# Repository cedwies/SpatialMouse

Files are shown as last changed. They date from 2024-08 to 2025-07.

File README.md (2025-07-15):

## Spatial Mouse:

The spatial mouse is a clever connection between a computer mouse and a VR controller. 

There are some useful use cases for this product. 
A good example could be a designer, who designs 3D objects on a virtual monitor. The designer can use the spatial mouse for his normal 2D design program but also lift it up and grab, drag and rotate the virtual object the designer is working on, without the need of taking off the VR glasses and looking for VR controller. 

Another, simpler use case could be someone working not at a the office with multiple monitors but in a café, where you dont have any external monitors. A virtual monitor setup would be nice. In this case this person could use the spatial mouse to perform the normal computer work but also control VR things like dragging screens and windows to another place or changing something in the virtual surrounding.

## Repository Structure

| Directory | Purpose |
|---|---|
| `Project` | Everything related to your project. |
| `Project/Concept` | Everything related to the concept or design of your project (ideas, drawings, mockups, mind maps, etc.). |
| `Project/Electronics` | Everything related to the electronics of your project (circuit diagrams, datasheets, etc.). |
| `Project/Mechanical` | Everything related to the mechanical aspect of your project (CAD, blueprints, datasheets, assembly, etc.). |
| `Project/Software` | The software aspect of your project. Most likely source code. |
| `Weekly Reports` | Weekly status updates as Markdown files. |
| `Weekly Reports/Figures` | Pictures or videos for your weekly reports. |

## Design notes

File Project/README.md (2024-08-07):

# PhysComp SS24 - SpatialMouse

The Spatial Mouse is a combination of a VR controller and a computer mouse. In the folder you can find some information about our current work.

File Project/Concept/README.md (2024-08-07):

# Spatial Mouse Concept

## Overview

The Spatial Mouse is an innovative input device that combines the functionality of a traditional computer mouse with a VR controller. This unique combination allows for seamless transitions between 2D and 3D interactions in virtual environments.

## Key Features

- Functions as a standard 2D mouse on flat surfaces
- Transforms into a 3D VR controller when lifted
- Seamless transition between 2D and 3D interactions
- Compatible with both traditional desktop applications and VR environments

## Use Cases

### 1. 3D Design and Modeling

Ideal for designers working on 3D objects in virtual environments:
- Use as a regular mouse for 2D design software
- Lift to manipulate 3D objects (grab, drag, rotate) without switching devices
- Eliminates the need to remove VR headset to locate separate controllers

### 2. Virtual Workspaces

Perfect for professionals working in mobile or space-constrained environments:
- Operate normally for standard computer tasks
- Easily control virtual monitors and windows in a VR workspace
- Adjust virtual surroundings without additional equipment

## Benefits

- Increased productivity by reducing device switching
- Enhanced workflow in mixed 2D/3D environments
- Improved portability for VR-enhanced work setups

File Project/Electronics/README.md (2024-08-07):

# PhysComp SS24 - SpatialMouse - Electronics

# Custom Sensor Integration

This project demonstrates the integration of custom sensors with a microcontroller board.

## Wiring Diagram

The included wiring diagram illustrates the connections between various components:

- Multiple sensor inputs (D6, D7, D8, D9)
- Power supply (VBUS)
- Ground (GND)
- Power supply (VIN)
- Additional modules (represented by rectangular blocks)

While the diagram is a simplified representation, it communicates the overall connection scheme, allowing for quick understanding and implementation.

## Physical Implementation

The accompanying photo shows the actual wiring implementation. Key features include:

- Multi-colored wires for easy identification
- Compact wiring layout to minimize space requirements
- Use of standard connectors for modularity and ease of assembly/disassembly

This physical setup demonstrates the transition from concept to practical application.

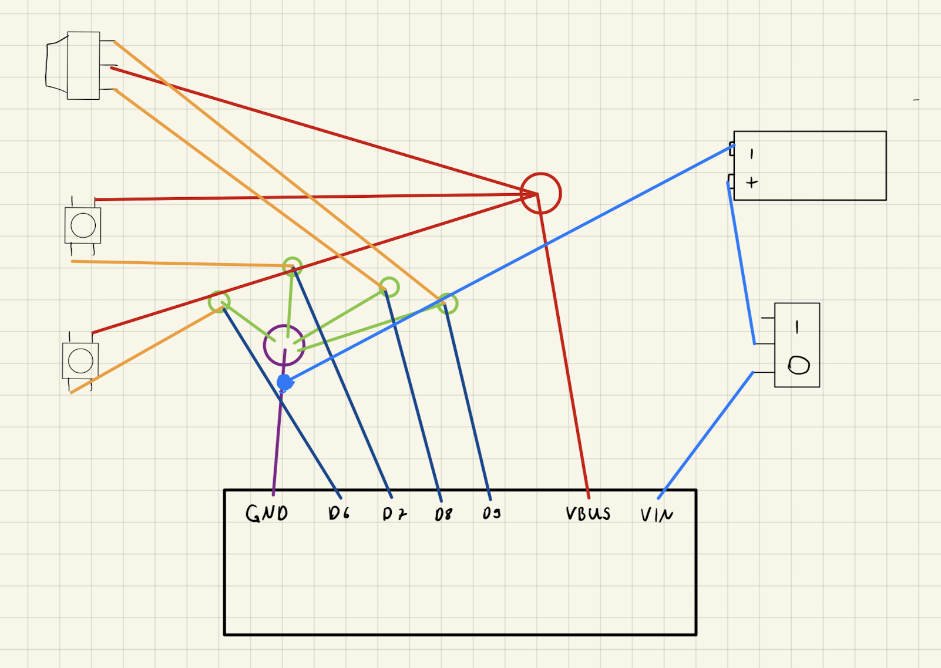
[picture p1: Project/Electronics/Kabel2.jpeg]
Kabel


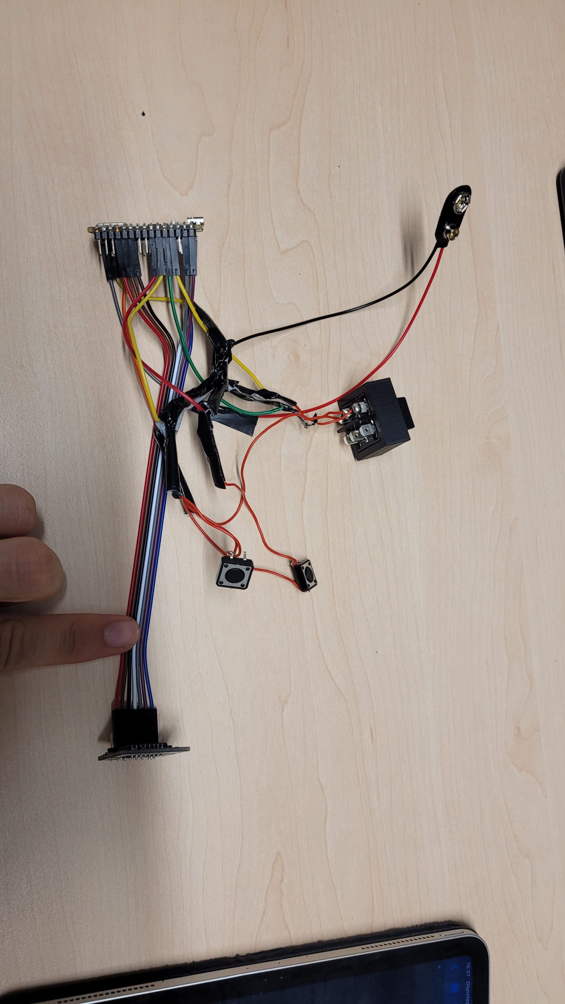
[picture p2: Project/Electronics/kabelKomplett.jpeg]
Kabel2


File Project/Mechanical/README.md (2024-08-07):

# PhysComp SS24 - SpatialMouse - Mechanical

Below you'll find images and the Fusion 360 code for the 3D model of our second iteration Spatial Mouse prototype:

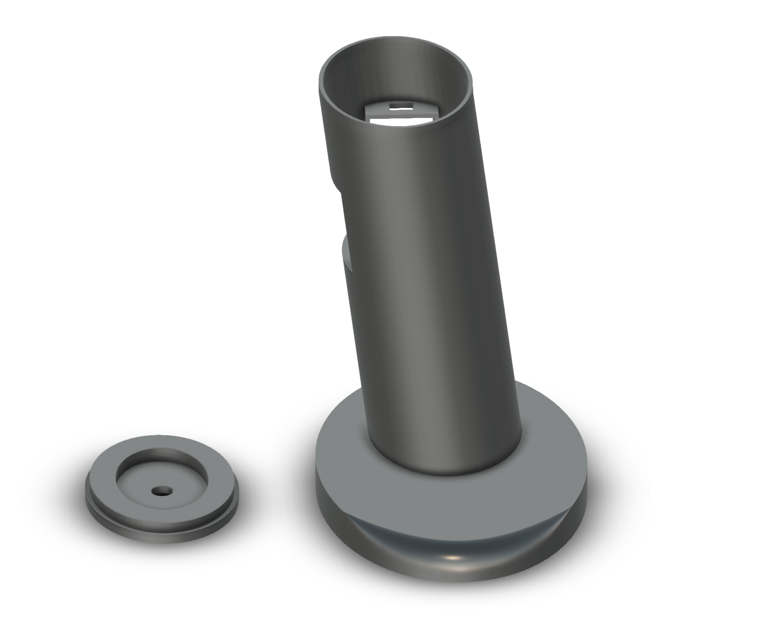
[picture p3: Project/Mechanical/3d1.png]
SpatialMouse1


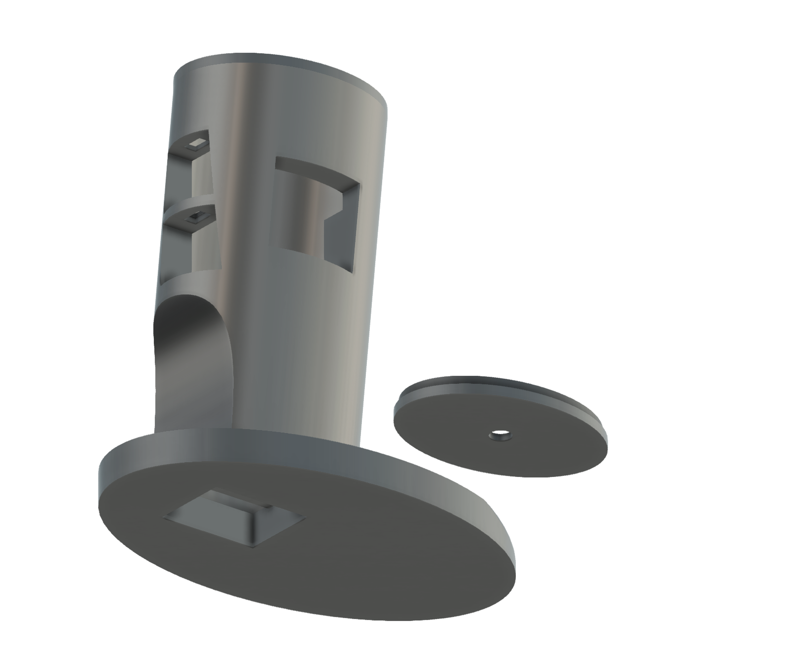
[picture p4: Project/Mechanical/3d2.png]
SpatialMouse2


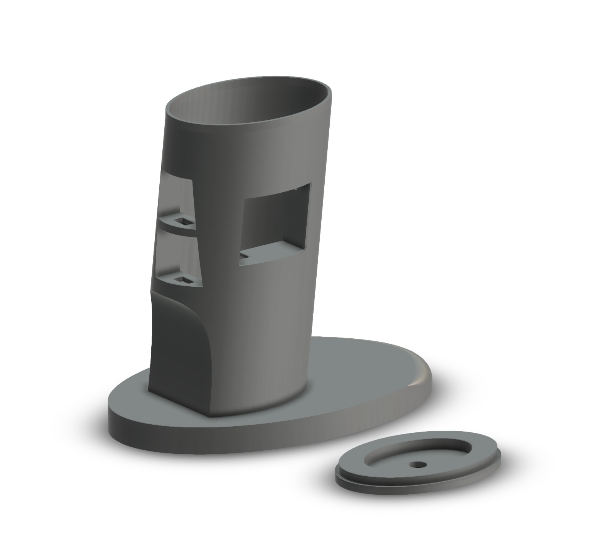
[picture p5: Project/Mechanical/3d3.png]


This is our newes iteration of the 3D model for the Spatial Mouse:

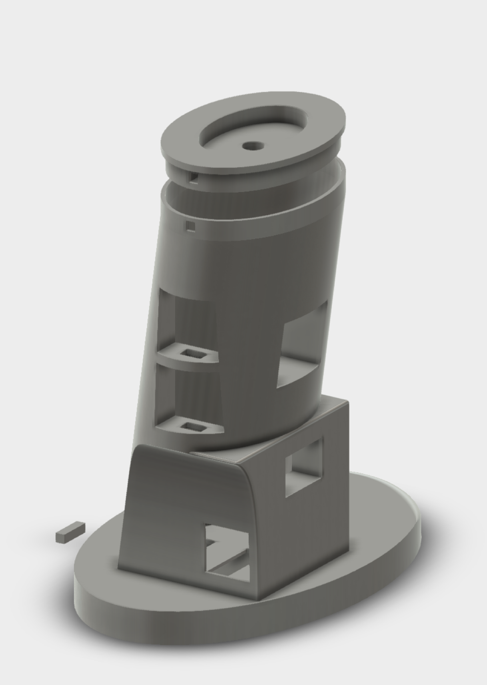
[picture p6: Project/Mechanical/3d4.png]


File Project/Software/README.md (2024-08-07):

This section contains the code for both the Arduino microcontroller and the Unity project, which together form the core components of our custom VR input device system.

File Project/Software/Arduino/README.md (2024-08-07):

# PhysComp SS24 - SpatialMouse - Software

This section contains the code for the Arduino Nano ESP32. The code operates a Bluetooth mouse featuring two buttons, a scroll switch, and a mouse sensor. The mouse sensor detects whether the device is on the ground or in the air and transmits this information to another Bluetooth device. When the mouse is lifted, the buttons have alternative functions and do not operate as standard mouse clicks.

We worked with code from here (for our mouse sensor): 
https://github.com/mrjohnk/PMW3389DM

And with the BLE Mouse Library:
https://github.com/T-vK/ESP32-BLE-Mouse

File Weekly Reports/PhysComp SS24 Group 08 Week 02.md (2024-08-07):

# PhysComp SS24 Group 8 - Week 1

## Progress Report

### What we achieved this week

This week, our task was to work with Arduino and learn how simple electric circuits work. Since we both don't have any experience with hardware and micro controllers, it was new and interesting. We started with the basic tutorials on the Arduino page. After learning the basics of how a simple electric circuit is built and what different components have what functionality, we started to build our own few circuits (see pictures). At the end of this session, we came to the section where we had to run a test program on an Arduino micro controller, where the LED on the controller started to blink. After achieving this, the session was over.

AWeekOne
AWeekOne

### What we could not achieve this week

Unfortunately, we were unable to completely finish the course. We needed some time to actually figure out how all individual components work together. One mayor reasons for this was that we needed a substantial amount of time to get things up and running, especially finding the correct online course took us some time. 

However, the main problem was that we frequently got caught up in playing around with the components. We did not follow the course strictly, but rather started to experiment a lot at certain times. While we believe this to be a good way of learning, for the next time we would try to adhere to the course a little bit more strictly.

### What we plan to do for the coming week

We would like to continue to familiarise ourselves with the hardware, especially by experimenting with the Arduino micro controller. Up to this point we only worked with non-programmable electric circuits. We are excited to bridge the gap between programming and hardware, in order to maximise our expertise for the upcoming weeks and primarily the final prototype.

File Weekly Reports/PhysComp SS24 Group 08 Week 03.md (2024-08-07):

# PhysComp SS24 Assignment - Week 3

> **Deadline:** 07.05.2023, 23:59 CEST

## Weekly Progress Report

1. **First concept:** 

We started by brainstorming different ideas and concepts in order to create viable sketches and to rule out poor design choices. To achieve this, we focused on asking ourselves "What is important?". By asking that question repeatedly, we found that ease of use, low weight and ergonomic feeling should be our main priorities, since users will likely hold the device in their hands for a prolonged period of time.

Regarding our sketches, we designed them by forming them out of knead. We found this to be the best approach, as we could easily check how they feel inside a users hand.  This would not have been possible with drawings. We created 4 different models, which were the results of our brainstorming session.

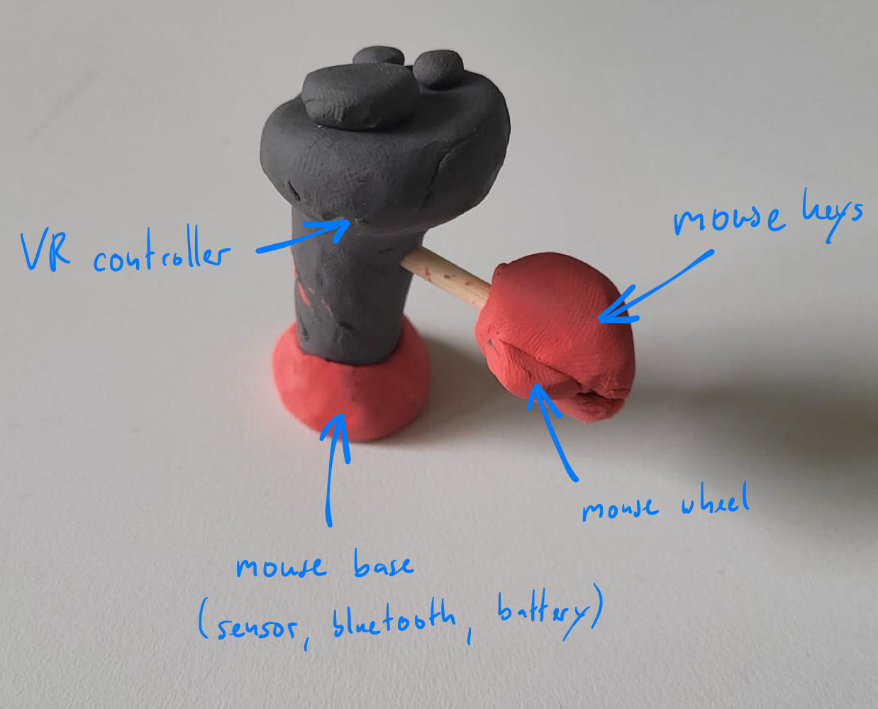
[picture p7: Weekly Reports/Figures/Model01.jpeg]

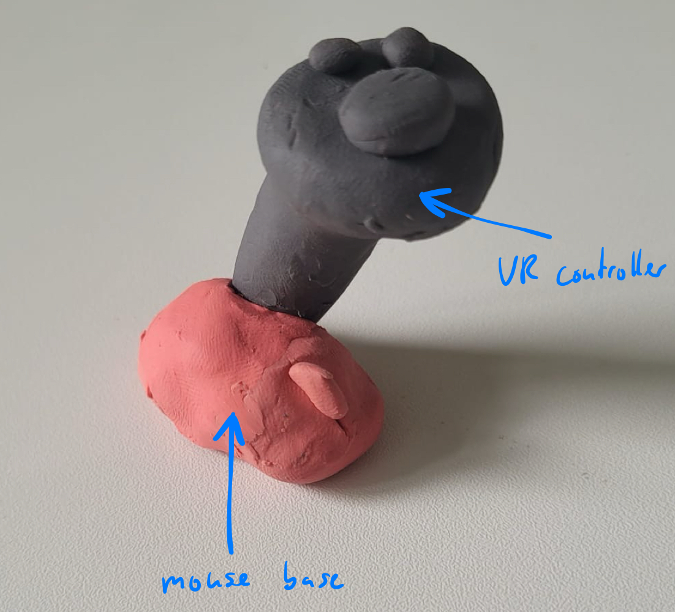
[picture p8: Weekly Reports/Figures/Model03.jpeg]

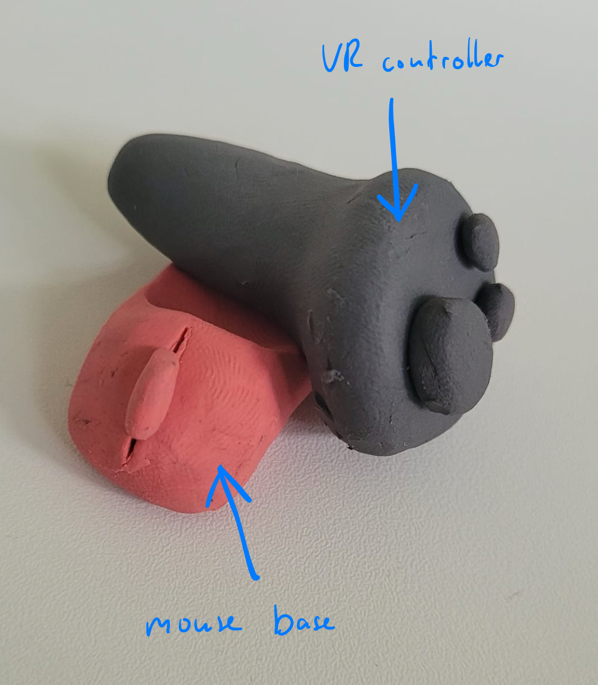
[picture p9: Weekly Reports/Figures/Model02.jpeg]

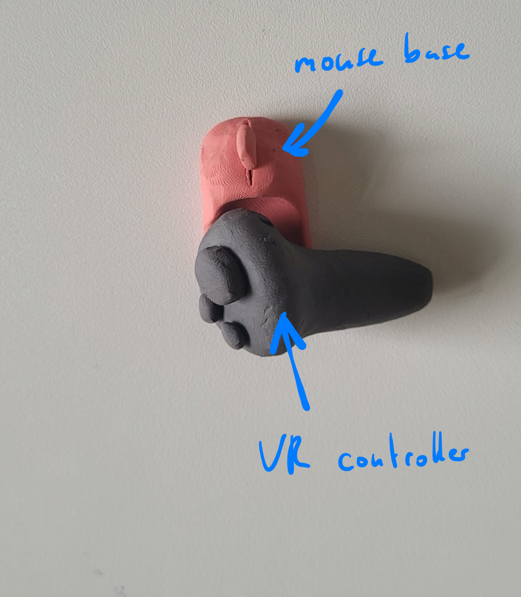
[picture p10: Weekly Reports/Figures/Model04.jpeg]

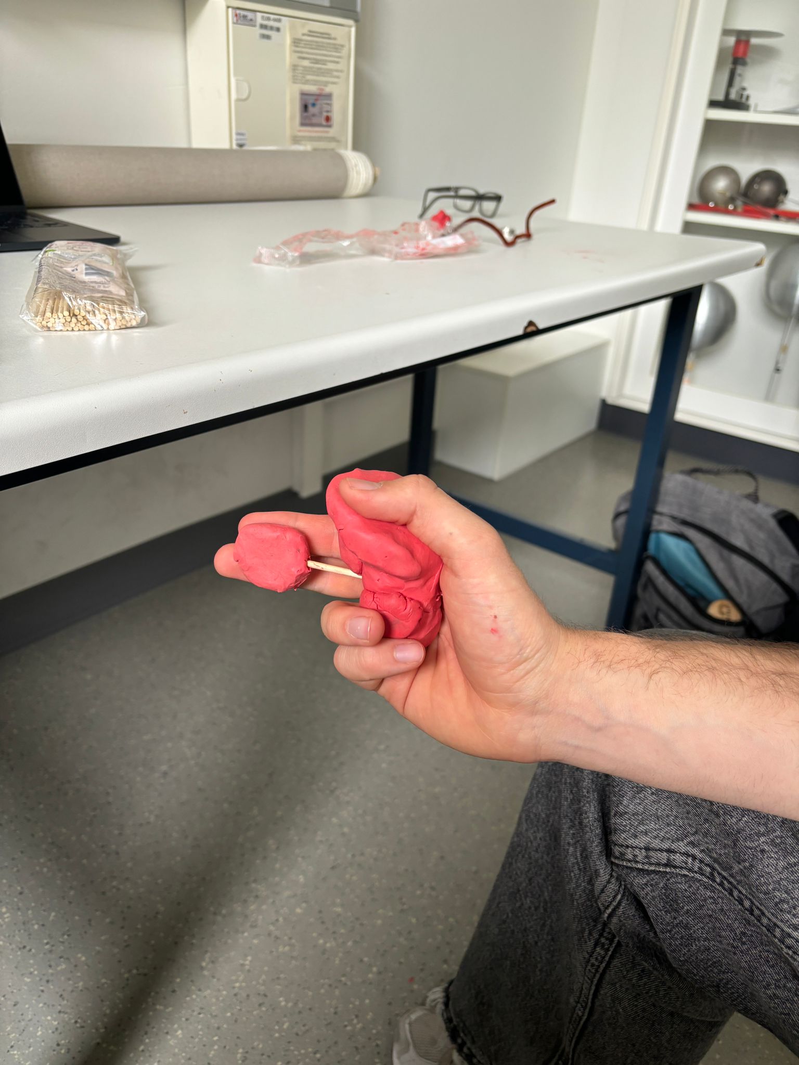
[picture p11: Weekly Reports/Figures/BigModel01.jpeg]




Picture 1: User (wearing a VR-Glasses) using a mouse

Picture 2: The user has to take down the VR-Glasses in order to switch to the VR-Controller

Picture 3: User using a VR-Controller as input device

Picture 4: User has to take down VR-Glasses again in order to switch the input device

Picture 5: 2-in-1 Spatial-Mouse gets handed to the user

Picture 6: User throws Mouse and VR-Controller in the trash

Picture 7: User using Spatial-Mouse as a mouse

Picture 8: User using Spatial-Mouse as a VR-Controller

2. **Objects/Idea Collection:** 







3. **First component list** 

| Item | Status | Example |
|---|---|---|
| VR Controller | Already ordered | - |
| Mouse (Bluetooth) | Already ordered and arrived | - |
| Modelling material (Knead) | Not yet ordered | https://rb.gy/tvhnu7 |
| 3D printing material | Not yet ordered | https://rb.gy/vp8pg3 |

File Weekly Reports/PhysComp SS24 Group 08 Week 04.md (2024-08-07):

# PhysComp SS24 Assignment - Week 4

> **Deadline:** 14.05.2024, 23:59 CEST

## Weekly Progress Report

1. **Progress report:**

    We continued to think about our prototype. After brainstorming a little, we looked for an old plastic film to protect the VR controller we brought today. With the wrapped-up controller, we tried out different creations of how we could combine it with a modified mouse.

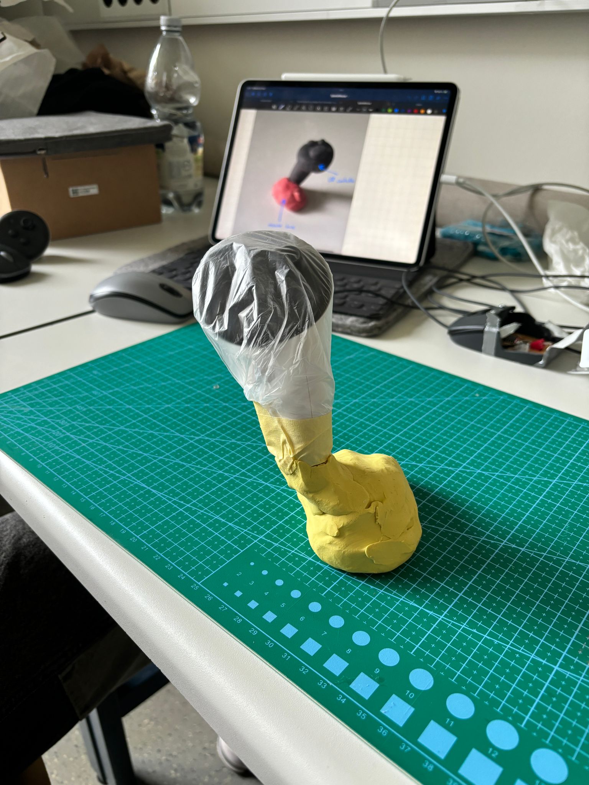
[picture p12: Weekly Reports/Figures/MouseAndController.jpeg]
    

    After a talk with Prof. Feutner we decieded to change our plans. While we were previously focusing on combining a mouse and a VR-Controller, we tried to deviate from this idea and tried to think more "outside the box". By planning on building the device ourselves (instead of just using a existing VR-Controller), we were able to come up with more unique shapes and new solutions (picture below). This week, we successfully thought about what would be needed to build our prototype. We especially focused on the components that we need for this task. The main change is, that we have a completely new shape, rather than working with finished products.

    

    In this picture one can see our first ideas of how the Spatial Mouse could look like. One can also see the major differences compared to having the computer mouse and VR-Controller combined.

    Unfortunately, we were unable to find exact models of all the components we need. Some hardware components (such as the mouse sensor) are hard to find. Furthermore, while we have a good general understanding of what we are trying to achieve, we did not yet go into very much detail. Part of the reason is, that going into detail requires us to know our hardware components. 

    Our plans for next week are to finish the list of hardware components that we need to order and to decied on one of the shaped for our first prototype (At the moment we are leaning towards the right one).

    **Norman's Design Principles:**

    Visibility: We have made the buttons and switches on the device clearly visible and easily distinguishable. The input buttons (primary and secondary trigger) shall be placed in similar locations compared to a traditional VR-Controller, making the purpose evident to the user.

    Feedback: We incorporate tactile feedback into the buttons and switches, providing a satisfying click or bump when activated. While a traditional VR-Controller has buttons with gradual pressability, we will for now focus on "all or nothing" buttons, for improved feedback.

    Constraints: We have designed the device with physical constraint that guide the user's actions. The shape and size of the device naturally fit the user's hand, encouraging a comfortable and ergonomic grip. Furthermore, the mouse plate at the bottom does not allow for any other sensable way of putting the device on the table, other that how it is intended to be placed.

    Mapping: We have mapped the devices controls to closely match the user's expectations and mental models. The input buttons will be placed similarily to the buttons of traditional VR-Controllers, and the mouse wheel will have an almost identical shape compared to traditional mouse wheels, following established conventions and best practices.

    Constistencty: The behaviour of the buttons shall remain consistent in each mode. For example, one mouse button should always be for left click, while the other button should always be for right click. In VR mode, the buttons consistently map to specific actions or functions within the virtual environment, such as grabbing objects or navigating menus.

    Affordance: The physical design of the device affords its intended use. The shape and form factor of the stick suggest that it can be gripped and manipulated like a handheld controller. The flat mouse plate on the bottom affords placement on a desk surface for mouse functionality. The buttons and switches are sized and shaped to invite pressing, clearly indicating their interactive nature.

    Siginifiers: We have included clear signifiers on the device to communicate its capabilities and mode of operation. The mode switch button shall be distinctively marked to signify its purpose. The device's overall appearance and branding shall signify its dual functionality as a VR-Controller and computer mouse.

2. **Refined component list:** 

| Item | Status | Example |
|---|---|---|
| Vive Tracker | Present at University | - |
| Arduino ESP 32 | Not yet ordered | https://shorturl.at/juJKL |
| Mouse Sensor (including breakout board) | Not yet ordered | Still searching for an example, hard to find |
| 3D printing material | Present at University | - |
| Buttons | Still deciding which types we need | - | 
| Battery | Not certain which power supply is needed | - |

Note: The main components (which have to be ordered) are the Arduino ESP 32, the mouse sensor and the breakout board. 
We expect to find everything else at the University (at least everything that we think is needed so far, such as cables etc.). Next week, we'll take a closer look at our component list and aim to wrap it up.

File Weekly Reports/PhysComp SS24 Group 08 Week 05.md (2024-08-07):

# PhysComp SS24 Assignment - Week 5

> **Deadline:** 21.05.2024, 23:59 CEST

## Weekly Progress Report

1. **Project Concept**

    After our presentations, we first discussed the feedback we received. Then, we went downstairs to gather some materials for building a prototype of our new design idea. Once we found the materials we needed, we quickly started working on the sketch.
    
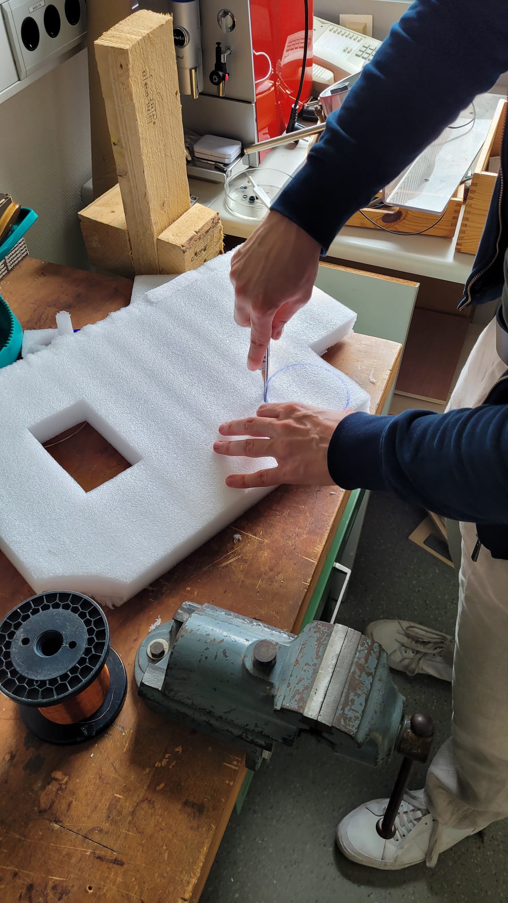
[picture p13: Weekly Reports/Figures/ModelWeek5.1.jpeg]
    

    Figure 1: Creating our first physical prototype based on our new design.
    
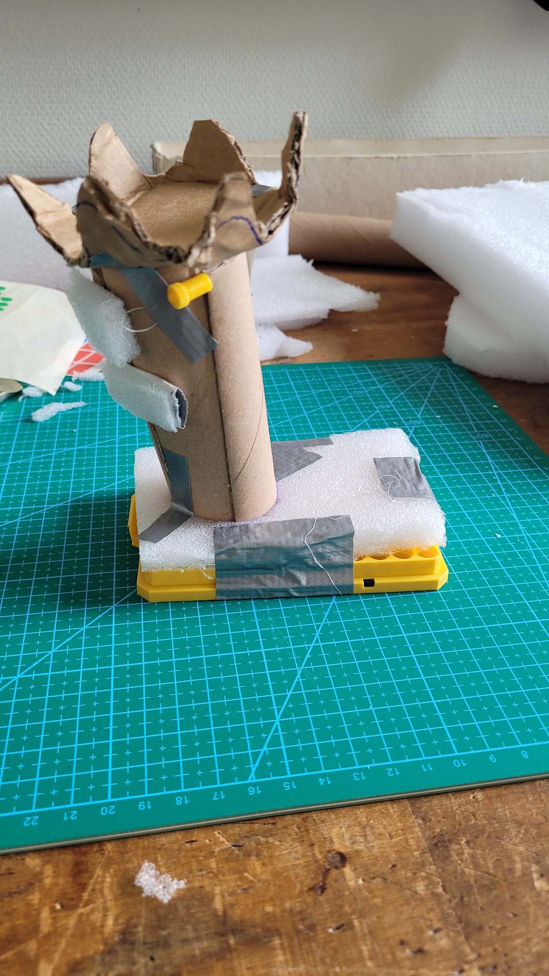
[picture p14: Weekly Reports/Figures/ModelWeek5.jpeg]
    

    Figure 2: Finished the first physical protoype. White buttons in the front, plate for mouse sensor at the bottom, yellow pin representing the mouse wheel.
    The crown on top represents the vive tracker.
    
    We were satisfied with the result, especially since we were unsure about how the mouse positions would feel. One problem we realised after building the prototype was that different hand sizes affect how well you can use the spatial mouse. We will have to find a way to allow hands of different sizes to comfortably grab the spatial mouse.

    After building our prototype, we talked to two other groups, exchanged feedback, and showed both of them our paper model of the spatial mouse. This was helpful as it provided additional feedback and led to interesting discussions about our design choice. We also tested the tilted (visible in the picture of our prototype) design which was suggested as feedback by group 4 and were surprised by the difference regarding the feeling when one is grabbing onto the device. Due to the small tilt, the spatial mouse feels more natural and the stress on the users wrist is reduced.

    Unfortunately, we did not have time to discuss the component list. We will try to focus on that again in the future.

2. **Current component list:** 

| Item | Status | Example |
|---|---|---|
| Vive Tracker | Present at University | - |
| Arduino ESP 32 | Not yet ordered | https://shorturl.at/juJKL |
| Mouse Sensor (including breakout board) | Not yet ordered | Still searching for an example, hard to find |
| 3D printing material | Present at University | - |
| Buttons | Still deciding which types we need | - | 
| Battery | Not certain which power supply is needed | - |

Note: The main components (which have to be ordered) are the Arduino ESP 32, the mouse sensor and the breakout board. 
We expect to find everything else at the University (at least everything that we think is needed so far, such as cables etc.). Next week, we'll take a closer look at our component list and aim to wrap it up.

## Feedback Report
1. **Concept Presentation**

We received helpful and insightful feedback on our concept presentation. First, feedback was given regarding the buttons (user inputs) of our device.
While we already thought about not using buttons with gradual feedback on purpose, clues were given about which button would be serving as the left or right mouse click respectively. By asking the question "Which button do you plan on using for the left mouse click?" it was brought to our attention that we did not yet think this through enough and we might need to spend a little bit more time on that matter.

Next, it was mentioned that the spatial mouse may lead to an urge of lifting the device even when making use of the computer mouse use case. This would be far from ideal. However, when handing the prototype to other groups, we were not able to confirm this feedback. So while we will keep an eye out for this issue, we are not going to immediately deal with it, since it may not actually be a problem when using the device.

Lastly, we received feedback on the general design of our spatial mouse. We were asked what other shapes there might be, since the shapes of our prototypes were either strongly inspired by a computer mouse or by a VR controller. This feedback was familiar, since this was our main issue for the past two weeks. We were asked again for "outside of the box" solutions. 

Regarding solutions, one might be able to incorporate buttons which support two modes. One with tactile feedback, as well as one mode where the buttons only give gradual feedback. The user can then switch between the two modes, depending on which feedback he wants to receive upon pressing the buttons. Furthermore, one can think about new shapes again. Although we already thought about shapes extensively, there might be creative and ideally suited designs which we did not yet uncover. However, this would only be hypothetical, since after evaluating thoroughly, our current design is the most promising solution.

2. **Peer Evaluation**

For the peer evaluation we partnered up with Group 2 and 4.

With both groups we handed over our prototype and allowed them to play around freely, without giving them too many hints about how the device is intended to be used. Fortunately, both groups intuitively grabbed the device in the way it was intended to, placing their fingers on the correct buttons. This was a "silent" feedback for us, that the current shape of our spatial mouse successfully invites for a correct usage.

Both groups mentioned the ergonomic feeling during usage. While group 4 only suggested we might incorporate a small tilt for a more natural feeling, group 2 was sceptical at first regarding the vertical use of a computer mouse. They mentioned that a user might need some time to adjust to this new way of interacting with a computer mouse, but agreed that this might be a less significant issue when we showed them that there are vertical computer mouses for ergonomical reasons on the market. Another suggestion was that maybe one can achieve a design, were the user can turn the device in order to be able to use the mouse in the traditional position (horizontal), i.e. by turning the device 90 degrees, while making sure that the user does not have to change his grip. This feedback was again driven by the way in which they currently interact with a computer mouse but confirmed our assumption, that the ability to have one grip for both use cases is an essential feature and should be focused during further development of our prototype. 

Regarding given feedback for group 4, we evaluated the position of their control panel. While it is easily accessible when located on one of the arm pits, the arm pit can no longer be used to rest on. We suggested sticking it to the side of an arm pit and allow it to be flipped up and down when it is (not) needed. We also questioned the use case of the "lost chair" function, which shall allow the chair to come to the user on its own. We argued that we do not think that this feature will be used frequently, since we do not ask ourselves "where is my chair right now?". Almost every time we exactly know where our chair is located. Group 4 appreciated our feedback and told us, the feature could be useful for blind people. We agreed to the usefulness of such a feature for blind users, but also mentioned that blind users cannot really interact with a control panel which is not adapted to blind users, so they should pay attention to this detail. 

Group 2 asked our opinion on where to put the electronics in their device. While their current favourite was a circular plate on the bottom of the glass, we argued that this design can lead to several problems. Firstly, one has to be careful not to make the device too heavy. Users will lift the glass frequently and when the glass becomes too heavy, a user might be annoyed. Secondly, the circular plate had a larger diameter than the glass itself (at least in their prototype). In our feedback we mentioned that tables can be quite full with plates, multiple wine (and normal) glasses, forks, etc. So it would be ideal if the device does not need any additional horizontal space (vertical space is less tragic in our opintion). All in all our feedback focused on the importance of keeping the size which needs to be added to the glass to a minimum.

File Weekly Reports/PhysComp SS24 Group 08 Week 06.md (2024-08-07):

# PhysComp SS24 Assignment - Week 6

> **Deadline:** 04.06.2024, 23:59 CEST

## Weekly Progress Report
1.	**3D Printing:** Post *screenshots* of your 3D model(s) and briefly describe what you did, or whether you struggled with something. Upload your final *3D your models*, so we can print all next week. (Once it's done, please add a *photo* of the resulting print to document the outcome of your first 3D printing exercise.)

We both had a very similar approach regarding the design of our mug. We started by creating a cylinder and used the "Shell" command to create a hollow cavity within that cylinder. Next, we used the drill feature to create a hole at the bottom. We then continued to create a 2D sketch for the handle, which we then extraploated. After combining the two components, we extensively used "Fillet" command to smooth out the edges. 

A major difficulty was that we needed some time to figure out how to combine the two components (cylinder and handle) together. Furthermore, we found the navigation of "Autodesk Fusion" to be complicated and confusing. However, we already argued that over time, one has the possibility to become much more efficient in designing even more complicated 3D models.







2.	**Progress Report:** What have you achieved this week with regards to your project? As usual, if your *concept* has changed, briefly describe this (and post pictures). Also, report on your progress in *developing your prototype* or *acquiring equipment*.

We were able to familiarize ourselves with designing 3D models, which can then be printed by 3D printers. We are confident, that we are now able to design the prototype of our spatial mouse properly. Additionally, we ordered the core component of the spatial mouse (mouse sensor) which need a substantial amount of delivery time (shipped from Canada). We were not able to completely agree on other components such as mouse wheel and buttons. However, we do not think that this is a big problem, since these components are available in stores which ship from Germany, therefore having a significantly shorter delivery time.

Regarding the development of our prototype, we were successful on deciding our final design choice, which was a great relief, since it now allows to proceed on our project by taking the next steps into the right directions.

## Project Plan for Prototype Development
It’s half time! Now it’s important to reflect and budget your remaining resources.

3.	Specify at least **4 milestones** for your prototype development (from now until the end of this course). Briefly describe what needs to be achieved for each. 

**Milestone 1: Decide on a Design**

Our first milestone is to finalize the design concept for our spatial mouse. We need to review all the different design ideas we've discussed over the past few weeks. The design we choose will become the prototype we aim to build. We will think through this design in detail, planning where each button will be placed, how the battery will be integrated, and how the cables will connect to each component. This detailed planning will help ensure that our prototype is both functional and user-friendly.

**Milestone 2: Test Functionality**

For our second milestone, we need to ensure that our first prototype functions as intended. We will assemble the components and test the prototype to see if it meets our desired functionality. This stage is crucial because it allows us to identify and fix any issues with the components or their assembly before moving on to the next step.

**Milestone 3: Build the Components into a Prototype**

In this milestone, we aim to find a shape for the spatial mouse that accommodates all the components. We will assemble everything into a body and test its usability. This step helps us identify any improvements needed in the design. By using this prototype, we can make adjustments and refinements to enhance the overall design and functionality.

**Milestone 4: 3D Print the Spatial Mouse**

Our final milestone is to 3D print the refined design from Milestone 3. After printing the final shape, we will assemble all the components into and onto the 3D printed body. Our goal is to have a fully functional spatial mouse prototype that works as intended. This step will bring together all our efforts and allow us to see the final product in action.

Unfortunately, our product does not allow for any functionality to be faked, since the a proper demonstration requires both the computer mouse and the VR controller to work correctly. Only then will users be able to fully evaluate our final prototype.

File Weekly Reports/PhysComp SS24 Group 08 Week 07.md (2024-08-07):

# PhysComp SS24 Assignment - Week 7

> **Deadline:** 11.06.2024, 23:59 CEST (Sorry, assignment was delayed. Deadline is extended.)

## Weekly Progress Report
1.	**Soldering exercise**: Report on your soldering exercises (pictures and text). What was your experience, what challenges did you face, what was the outcome?

### Soldering Project Summary

The soldering exercise was really interesting and helpful. Unfortunately, Cedric could not join us this week, so Robin worked with Paulina in the three-person group.

Following the instructions from the video, we began soldering all the components together. We carefully ensured that each component was placed in the correct spot.

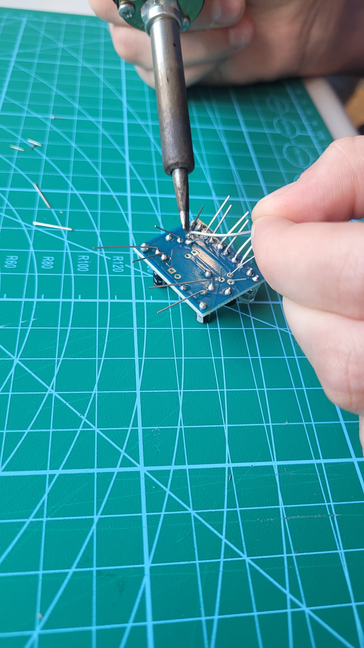
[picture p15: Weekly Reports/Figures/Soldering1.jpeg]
Soldering the last component


*Picture of the last component being soldered to the board*

After completing the soldering, we connected the board to a power source to check if it worked correctly. It did! We then trimmed all the unnecessary metal pieces, and the board looked like this:

<div style="display: flex; justify-content: space-between;">
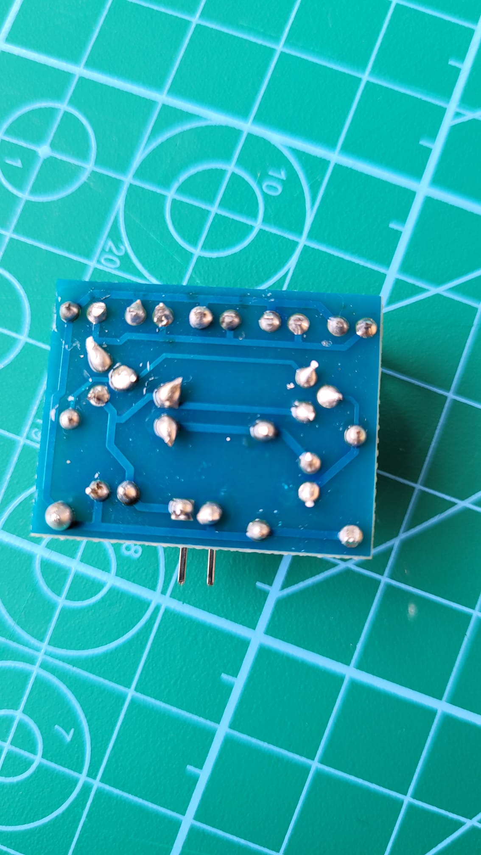
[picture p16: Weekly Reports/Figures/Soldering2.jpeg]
Back of the board
  
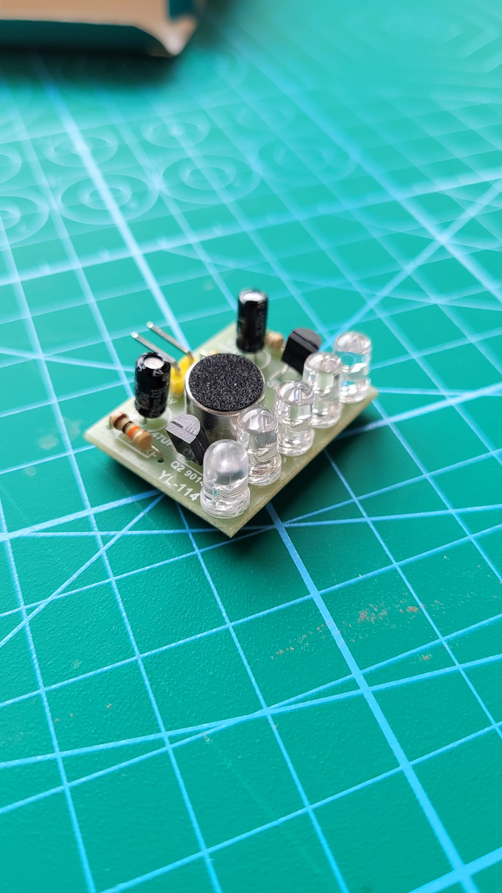
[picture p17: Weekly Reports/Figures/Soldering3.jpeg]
Front of the board
  
</div>

*The back and front of the board*

Afterwards, we tested our final product to see how well it worked. We were very pleased with the results.

Testing the final product

2.	**Progress Report:** What have you achieved this week with regards to your project? As usual, if your *concept* has changed, briefly describe this (and post pictures). Also, report on your progress in *developing your prototype* or *acquiring equipment*.

This week, we continued searching for components and finalized our "want to oder" - collection. We ordered the remaining hardware devices, and the good news is that they will arrive before next week's session.

Unfortunately, this week we were still waiting for these componets we ordered, so we could not start to assable the hardware together. Next week, the fun will begin!

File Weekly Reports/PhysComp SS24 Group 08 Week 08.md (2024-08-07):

# PhysComp SS24 Assignment - Week 8

> **Deadline:** 18.06.2024, 23:59 CEST

## Weekly Progress Report
1.	**Progress Report:** What have you achieved this week with regards to your project? As usual, if your *concept* has changed, briefly describe this (and post pictures). Also, report on your progress in *developing your prototype* or *acquiring equipment*.

This week the mouse sensor finally arrived and we were able to start off with our first functionality tests. We started by testing every component (buttons, toggle switch, mouse sensor) individually in order to make sure how every single component works. During the test of the buttons which we ordered we found out that the state between "pressed" and "not pressed" is not well separated. That means if one pushes the button, instead of "not pressed" -> "pressed" -> "not pressed", the state switches multiple times during one press (e.g. "not pressed" -> "pressed" -> "not pressed" -> "pressed" -> "not pressed"). Since this is far from ideal for the usage in both a VR controller and computer mouse, we may need to replace the buttons with ones which have a clear tactile feedback.

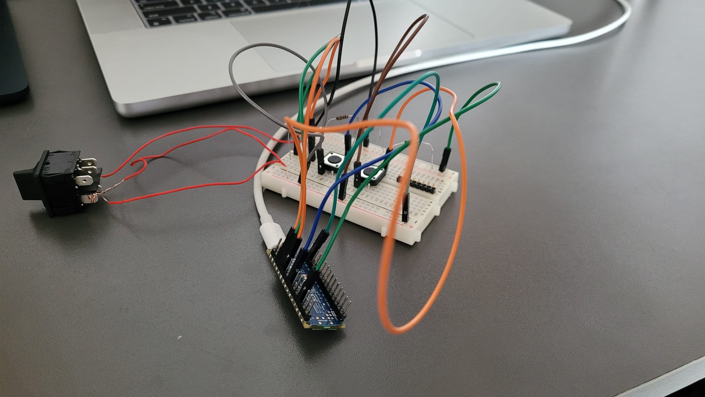
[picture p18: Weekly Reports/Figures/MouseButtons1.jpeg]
MouseButtons1


Additionally, we thought about how to implement the mouse wheel. Since in our design the mouse wheel is located at the side of our device, we ordered a tactile switch which (when not pressed) jumps back into a neutral position. The idea was to use a constant scroll speed when the switch is pressed up/down. However, since a substantial amount of force is required and the scroll speed cannot be altered, we are considering to replace the switch with a joystick for an improved scrolling experience. 

Furthermore, we were able to send bluetooth signals from our Arduino ESP32 Nano to our computers. We designed a left and right mouse button, and were able to use them as the input on our MacBooks. In order to emulate a complete computer mouse we then needed to get the mouse sensor to work. This was by far the most complicated part, since the sensor was the most complex hardware component until this point. 

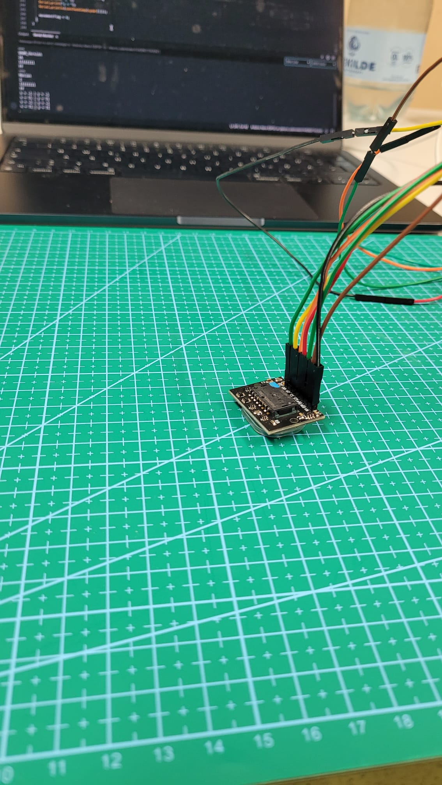
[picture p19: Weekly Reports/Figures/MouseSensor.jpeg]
MouseSensor


However, we were successful in getting the sensor to work and even using it as a mouse via Bluetooth.

Mouse Sensor Demonstration

Most of the code was written by ourselves. For the PMW3389 Sensor we found a useful GitHub page, on which we found some code that helped us to setup the sensor.

**Our current code so far:**

<details>
<summary>Code</summary>

```cpp
#include <BleMouse.h>
BleMouse bleMouse;
#include <SPI.h>
#include <pgmspace.h>

// Registers
#define Product_ID 0x00
#define Revision_ID 0x01
#define Motion 0x02
#define Delta_X_L 0x03
#define Delta_X_H 0x04
#define Delta_Y_L 0x05
#define Delta_Y_H 0x06
#define SQUAL 0x07
#define Raw_Data_Sum 0x08
#define Maximum_Raw_data 0x09
#define Minimum_Raw_data 0x0A
#define Shutter_Lower 0x0B
#define Shutter_Upper 0x0C
#define Control 0x0D
#define Config1 0x0F
#define Config2 0x10
#define Angle_Tune 0x11
#define Frame_Capture 0x12
#define SROM_Enable 0x13
#define Run_Downshift 0x14
#define Rest1_Rate_Lower 0x15
#define Rest1_Rate_Upper 0x16
#define Rest1_Downshift 0x17
#define Rest2_Rate_Lower 0x18
#define Rest2_Rate_Upper 0x19
#define Rest2_Downshift 0x1A
#define Rest3_Rate_Lower 0x1B
#define Rest3_Rate_Upper 0x1C
#define Observation 0x24
#define Data_Out_Lower 0x25
#define Data_Out_Upper 0x26
#define Raw_Data_Dump 0x29
#define SROM_ID 0x2A
#define Min_SQ_Run 0x2B
#define Raw_Data_Threshold 0x2C
#define Config5 0x2F
#define Power_Up_Reset 0x3A
#define Shutdown 0x3B
#define Inverse_Product_ID 0x3F
#define LiftCutoff_Tune3 0x41
#define Angle_Snap 0x42
#define LiftCutoff_Tune1 0x4A
#define Motion_Burst 0x50
#define LiftCutoff_Tune_Timeout 0x58
#define LiftCutoff_Tune_Min_Length 0x5A
#define SROM_Load_Burst 0x62
#define Lift_Config 0x63
#define Raw_Data_Burst 0x64
#define LiftCutoff_Tune2 0x65

// Set this to what pin your "INT0" hardware interrupt feature is on
#define Motion_Interrupt_Pin 2

const int ncs = 3;  // This is the SPI "slave select" pin that the sensor is hooked up to

byte initComplete = 0;
volatile int xydat[2];
volatile byte movementflag = 0;

// Be sure to add the SROM file into this sketch via "Sketch->Add File"
extern const unsigned short firmware_length;
extern const unsigned char firmware_data[];

const int buttonLeft = 6;
const int buttonRight = 7;
// const int scrollUp = 8;
// const int scrollDown = 9;

int buttonStateLeft = 0;
int buttonStateRight = 0;
int scrollUpState = 0;
int scrollDownState = 0;

// Forward declaration of UpdatePointer function
void UpdatePointer();

void setup() {
  Serial.begin(9600);
  while (!Serial.availableForWrite())
    ;

  bleMouse.begin();

  pinMode(LED_BUILTIN, OUTPUT);
  pinMode(buttonLeft, INPUT_PULLUP);
  pinMode(buttonRight, INPUT_PULLUP);
  // pinMode(scrollUp, INPUT_PULLUP);
  // pinMode(scrollDown, INPUT_PULLUP);

  pinMode(ncs, OUTPUT);

  pinMode(Motion_Interrupt_Pin, INPUT_PULLUP);
  digitalWrite(Motion_Interrupt_Pin, HIGH);
  // attachInterrupt(digitalPinToInterrupt(Motion_Interrupt_Pin), UpdatePointer, FALLING);

  SPI.begin();
  SPI.setDataMode(SPI_MODE3);
  SPI.setBitOrder(MSBFIRST);
  SPI.setClockDivider(SPI_CLOCK_DIV128);

  performStartup();

  delay(5000);

  dispRegisters();
  initComplete = 9;
}

void adns_com_begin() {
  digitalWrite(ncs, LOW);
}

void adns_com_end() {
  digitalWrite(ncs, HIGH);
}

byte adns_read_reg(byte reg_addr) {
  adns_com_begin();

  // Send address of the register, with MSBit = 0 to indicate it's a read
  SPI.transfer(reg_addr & 0x7f);
  delayMicroseconds(100);  // tSRAD
  // Read data
  byte data = SPI.transfer(0);

  delayMicroseconds(1);  // tSCLK-NCS for read operation is 120ns
  adns_com_end();
  delayMicroseconds(19);  //  tSRW/tSRR (=20us) minus tSCLK-NCS

  return data;
}

void adns_write_reg(byte reg_addr, byte data) {
  adns_com_begin();

  // Send address of the register, with MSBit = 1 to indicate it's a write
  SPI.transfer(reg_addr | 0x80);
  // Send data
  SPI.transfer(data);

  delayMicroseconds(20);  // tSCLK-NCS for write operation
  adns_com_end();
  delayMicroseconds(100);  // tSWW/tSWR (=120us) minus tSCLK-NCS. Could be shortened, but is looks like a safe lower bound
}

void adns_upload_firmware() {
  // Send the firmware to the chip, cf p.18 of the datasheet
  Serial.println("Uploading firmware...");

  // Write 0 to Rest_En bit of Config2 register to disable Rest mode.
  adns_write_reg(Config2, 0x20);

  // Write 0x1d in SROM_enable reg for initializing
  adns_write_reg(SROM_Enable, 0x1d);

  // Wait for more than one frame period
  delay(10);  // Assume that the frame rate is as low as 100fps... even if it should never be that low

  // Write 0x18 to SROM_enable to start SROM download
  adns_write_reg(SROM_Enable, 0x18);

  // Write the SROM file (=firmware data)
  adns_com_begin();
  SPI.transfer(SROM_Load_Burst | 0x80);  // Write burst destination address
  delayMicroseconds(15);

  // Send all bytes of the firmware
  unsigned char c;
  for (int i = 0; i < firmware_length; i++) {
    c = (unsigned char)pgm_read_byte(firmware_data + i);
    SPI.transfer(c);
    delayMicroseconds(15);
  }

  // Read the SROM_ID register to verify the ID before any other register reads or writes.
  adns_read_reg(SROM_ID);

  // Write 0x00 to Config2 register for wired mouse or 0x20 for wireless mouse design.
  adns_write_reg(Config2, 0x00);

  // Set initial CPI resolution
  adns_write_reg(Config1, 0x15);

  adns_com_end();
}

void performStartup() {

  adns_com_end();                        // Ensure that the serial port is reset
  adns_com_begin();                      // Ensure that the serial port is reset
  adns_com_end();                        // Ensure that the serial port is reset
  adns_write_reg(Power_Up_Reset, 0x5a);  // Force reset
  delay(50);                             // Wait for it to reboot
  // Read registers 0x02 to 0x06 (and discard the data)
  adns_read_reg(Motion);
  adns_read_reg(Delta_X_L);
  adns_read_reg(Delta_X_H);
  adns_read_reg(Delta_Y_L);
  adns_read_reg(Delta_Y_H);
  // Upload the firmware
  adns_upload_firmware();
  delay(10);
  Serial.println("Optical Chip Initialized");
}

void UpdatePointer() {

  if (initComplete == 9) {

    // Write 0x01 to Motion register and read from it to freeze the motion values and make them available
    adns_write_reg(Motion, 0x01);
    adns_read_reg(Motion);

    xydat[0] = (int)adns_read_reg(Delta_X_L);
    xydat[1] = (int)adns_read_reg(Delta_Y_L);

    movementflag = 1;
  }
}

void dispRegisters() {
  int oreg[7] = { 0x00, 0x3F, 0x2A, 0x02 };
  char* oregname[] = { "Product_ID", "Inverse_Product_ID", "SROM_Version", "Motion" };
  byte regres;

  digitalWrite(ncs, LOW);

  int rctr = 0;
  for (rctr = 0; rctr < 4; rctr++) {
    SPI.transfer(oreg[rctr]);
    delay(1);
    Serial.println("---");
    Serial.println(oregname[rctr]);
    Serial.println(oreg[rctr], HEX);
    regres = SPI.transfer(0);
    Serial.println(regres, BIN);
    Serial.println(regres, HEX);
    delay(1);
  }
  digitalWrite(ncs, HIGH);
}

int convTwosComp(int b) {
  // Convert from 2's complement
  if (b & 0x80) {
    b = -1 * ((b ^ 0xff) + 1);
  }
  return b;
}

void loop() {

  if (bleMouse.isConnected()) {

    UpdatePointer();

    if (movementflag) {

      movementflag = 0;

      if (convTwosComp(xydat[0]) != 0 || convTwosComp(xydat[1]) != 0) {
        bleMouse.move((convTwosComp(xydat[0]) / 5), (convTwosComp(xydat[1]) / 5));
        Serial.print("x = ");
        Serial.print(convTwosComp(xydat[0]));
        Serial.print(" | ");
        Serial.print("y = ");
        Serial.println(convTwosComp(xydat[1]));
      }

      delay(2);
    }

    unsigned long startTime;
    buttonStateLeft = digitalRead(buttonLeft);
    buttonStateRight = digitalRead(buttonRight);
    // scrollUpState = digitalRead(scrollUp);
    // scrollDownState = digitalRead(scrollDown);

    //mouse scroll up
    if (scrollUpState == HIGH) {
      Serial.println("Scroll up!");
      startTime = millis();
      while (millis() < startTime + 500) {
        bleMouse.move(0, 0, 1);
        delay(100);
      }
    }

    //mouse scroll down
    if (scrollDownState == HIGH) {
      Serial.println("Scroll down!");
      startTime = millis();
      while (millis() < startTime + 500) {
        bleMouse.move(0, 0, -1);
        delay(100);
      }
    }

    //mouse left click
    if (buttonStateLeft == HIGH) {
      if (!bleMouse.isPressed(MOUSE_LEFT)) {
        Serial.println("Left click");
        bleMouse.press(MOUSE_LEFT);
      }
    } else {
      if (bleMouse.isPressed(MOUSE_LEFT)) {
        bleMouse.release(MOUSE_LEFT);
      }
    }

    //mouse right click
    if (buttonStateRight == HIGH) {
      if (!bleMouse.isPressed(MOUSE_RIGHT)) {
        Serial.println("Right click");
        bleMouse.press(MOUSE_RIGHT);
      }
    } else {
      if (bleMouse.isPressed(MOUSE_RIGHT)) {
        bleMouse.release(MOUSE_RIGHT);
      }
    }
  }
}
```
</details>

# Evaluation Plan

## Usability Testing with Think Aloud Study

For our evaluation, we will conduct a think aloud usability study to assess the intuitiveness and user experience of the spatial mouse. 

### Setup:
- The study will take place in the media room, which is equipped with the necessary Vive trackers. 
- Each study session will involve one participant at a time.
- We will have a desk setup in the media room with a screen that allows us to see what the participant sees in the VR environment.

### VR Environment (Wizard of Oz):
- The participant will be immersed in a VR space that simulates a desktop environment. 
- Desktop icons can be moved using normal mouse gestures. 
- When an icon is dragged out of the desktop, it will change shape to represent the corresponding window (e.g., Safari icon becomes a Safari window).
- The window can then be dragged around using the spatial mouse's VR controller functionality.

### Study Objectives:
Through this study, we aim to:
1. Assess the intuitiveness of the spatial mouse and clarity of its controls.
2. Gather feedback on the simplicity, comfort, and hand position when using the device.
3. Evaluate the user experience for different hand sizes.

### Study Task:
The study should contain a task for which the user needs to repeatedly switch between the computer mouse component and the VR controller component as the device input. This could be a sequence of moving icons out of the monitor and dragging windows and objects around in the environment.

### Participants:
- We will recruit participants who are either potential users of the spatial mouse (students or university staff) or professionals with extensive VR and VR controller experience (such as members of the HCI Department).
- Participants with prior experience using VR controllers would be beneficial for providing informed feedback.
- Professionals may offer more critical insights due to their expertise.

## Complementary Evaluation Techniques:

### 1. Survey:
We will conduct a survey to gain additional insights into the user experience of the spatial mouse. The survey will focus on the following aspects:
- Ergonomic feel of the computer mouse component
- Ergonomic feel of the VR controller component 
- Comparison between the traditional computer mouse and the spatial mouse
- For participants with VR controller experience: comparison between traditional VR controllers and the spatial mouse
- Scrolling experience and effectiveness

### 2. Benchmarking:
To assess the practicality of the spatial mouse, we will create a task for participants to complete using two setups:

a) Traditional computer mouse and traditional VR controller

b) Spatial mouse

We will measure the time taken by participants to complete the task in each setup. This benchmark will provide an indication of the spatial mouse's efficiency compared to traditional input devices.

By combining the think aloud usability study with surveys and benchmarking, we aim to gather comprehensive feedback on the spatial mouse's intuitiveness, ergonomics, and overall user experience. This evaluation plan will help us identify areas for improvement and validate the effectiveness of the spatial mouse as an input device for VR environments.

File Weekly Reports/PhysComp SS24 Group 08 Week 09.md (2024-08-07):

# PhysComp SS24 Assignment - Week 9

> **Deadline:** 25.06.2024, 23:59 CEST

## Weekly Progress Report
1.	**Progress Report:** What have you achieved this week with regards to your project? As usual, if your *concept* has changed, briefly describe this (and post pictures). 
Also, report on your progress in *developing your prototype* or *acquiring equipment*.

This week, we built upon our previous successes with mouse components and shifted our focus to integrating a Vive Tracker into our project. Our objective is to utilize the Vive Tracker as a VR controller by positioning it on top of our Spatial Mouse to enhance its functionality.

While we made some headway, we encountered challenges on the software side of the integration. We successfully established a connection with the Vive Tracker and achieved tracking capabilities. However, we're still working on integrating it into the Unity software to be able to read the tracking data of the Vive Tracker in Unity. Here, our goal is to configure it to function as a fully operational VR controller within our system.

This integration process has proven more complex than initially anticipated. Despite the hurdles, we remain committed to resolving these issues and are actively exploring various solutions to achieve our desired functionality.

Moving forward, our primary focus will be on overcoming the software obstacles preventing the Vive Tracker from operating as a VR controller in our setup. We're optimistic that with continued effort and problem-solving, we'll make significant progress in the coming week.

## Refine Evaluation Plan
2.	**Refine user task and measurements:** please revise and refine your evaluation plan based on the feedback you received. 
For most, this means to just specify the user task a bit better, so that you can really take away some meaningful learnings from the evaluation. 
Some of you may also wish to review the questions you ask participants (consider how you can find evidence that your prototype solves the "problem" you aim to address).

Specify our user task:
For our user study our idea was a task with which the user needs to repeatedly switch between the computer mouse component and the VR controller component as the device input. This could be a sequence of moving icons out of the monitor and dragging windows and objects around in the environment.
To specify this, we created a little sequence:
1. A red square spawns at a random position on the virtual monitor. With the help of the mouse function of the Spatial Mouse, this square can be moved on the virtual monitor and can also be dragged outside of the virtual monitor. When it is outside, it changes from a 2D square to a 3D cube, indicating it is now a 3D object, which can be moved with the VR controller function of the Spatial Mouse.
2. The user needs to move the red cube with the VR controller into a large blue 3D cube. When the red cube is inside the large blue cube, the subtask is finished, and the red cube disappears.
3. The red cube reappears on the virtual monitor at a new position, and the position of the blue cube also changes around the monitor.

This sequence should be repeated 5 times.

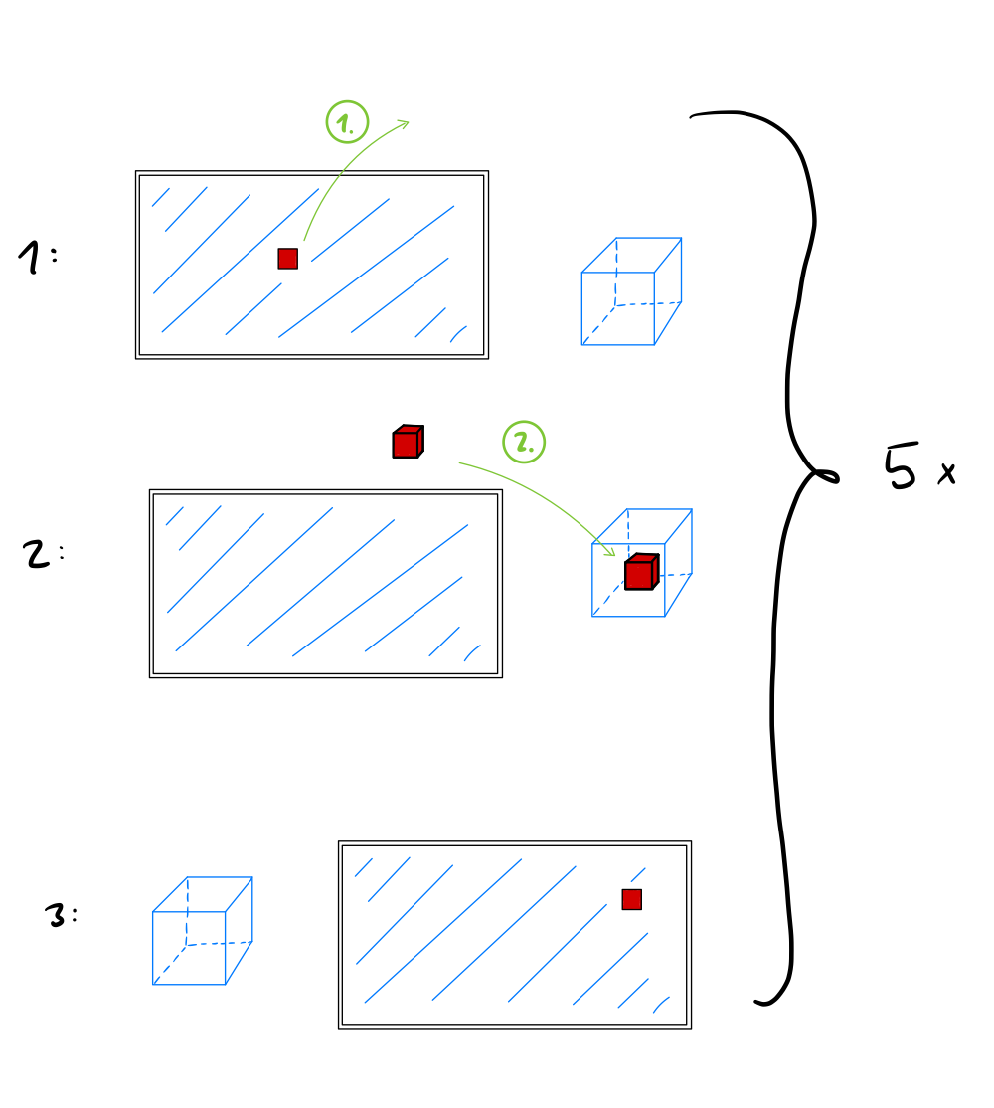
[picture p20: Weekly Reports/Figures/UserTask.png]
UserTask


With a user task like this we are focusing on repeatedly switching between the mouse function and the VR controller function to evaluate its effectiveness and user satisfaction. Additionally, we believe that incorporating a more "playful" task, such as a simple game, would be beneficial. However, since both of us have limited experience with Unity, we will proceed by attempting to implement this study task.

3. **Review Norman’s design principles**: Issues during interaction may occur if you fail to fully address these design principles. So, take advantage of the user evaluation to reflect on these again.
Look up the design priciples in the lecture slides and list at least 2 specific principles that are particularly relevant for your prototype at this stage. Then integrate a task or question in your evaluation plan that allows you to check whether you address these principles well. Describe your planned approach.

*Hint:* You will presumably all want to ensure visibility. You can evaluate this by observing and asking e.g., whether users understand the current system status or whether available functions are easily recognized/found.

### 1. Visibility:

Crucial since users need to clearly understand the current status of the device and easily recognize its functions.

Evaluation task: Ask users to identify and explain the purpose of each button or control on the device without prior instruction?

Planned approach: We will observe users when interacting with the Spatial Mouse for the first time and ask them to think aloud while exploring spatial mouse.
Make notes on which functions are directly apparent and which are not. 
Potential Questions: 
1. Can you tell me what this button does?
2. How would you use this device to perform Action X?
3. Is there any part of the device that is unclear to you ?

### 2. Mapping:

Evaluation task: Users perform a series of simple VR and mouse tasks, focusing on how well the physical movements translate to actions. 

Planned approach: We are going to set up an environment with basic interaction tasks (pointing, selecting, moving objects, etc). Next, we will ask the users to perform these tasks with the Spatial Mouse and observe their actions.

Potential Questions:
1. Describe how the movement of the device in your hand relates to what you see in VR?
2. What happens in VR if you press that button? Is it what you expected?
3. Tell me about any actions that felt natural/unnatural when using device?

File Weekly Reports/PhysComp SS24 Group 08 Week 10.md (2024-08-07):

# PhysComp SS23 Assignment - Week 10 Progress Report

## Progress Report

This week, we made significant strides in developing our spatial mouse project, focusing on both software and hardware aspects:

1. **VR Integration**: We successfully familiarized ourselves with Unity and SteamVR, crucial platforms for our project's functionality.

2. **Vive Tracker Implementation**: We configured the Vive Tracker to function as a VR controller. This is a critical component as it will be mounted on top of our spatial mouse.

3. **Hardware Integration**: With the Vive Tracker setup, we've concluded the hardware integration phase. All necessary components are now functional and ready for the next stage.

4. **Component Confinements**: We 3D printed small confinements for individual hardware devices (mouse sensor, tactile switch, and two buttons). This strategy allowed us to quickly iterate and modify sizes without printing the entire prototype. Each confinement took only 10-30 minutes to print, compared to the 8 hours required for a full prototype.

5. **Hardware Assembly**: We soldered the hardware components and wires together. Initially, we considered using a perfboard (a thin board similar to a breadboard where components can be inserted and soldered on the back). However, we were unsatisfied with the result, primarily due to the board's stiffness making it cumbersome to integrate into the spatial mouse. Instead, we opted to solder the components directly with wires, which proved easier to fit inside the hollow grip of the spatial mouse.

6. **First Prototype Printing**: We completed our first full prototype print. This process took about 8 hours but provided valuable insights. Upon completion, we identified several areas for improvement, particularly regarding the integration of hardware components into the printed structure.

7. **Design Iteration**: Based on our observations from the first prototype, we designed a modified shape. We initiated an overnight print of this revised prototype in preparation for our next lab session.

8. **Unity Project Expansion**: We expanded Robin's Unity project to accommodate the use case of the spatial mouse, which now works with the vive tracker and our self created mouse. Furthermore we created a study environment in Unity, where the participants need to solve four tasks.

### Picture Collection:

<details>
<summary>First Prototype</summary>

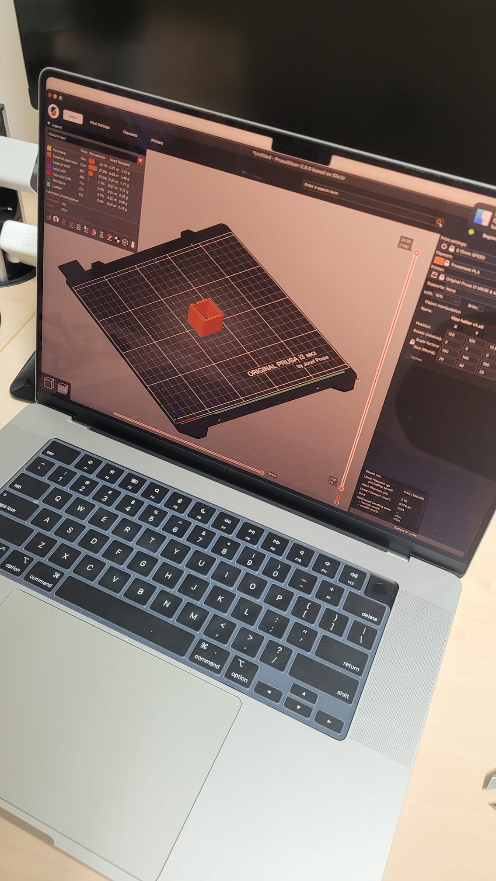
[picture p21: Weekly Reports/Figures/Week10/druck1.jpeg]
Confinement for Tactile Switch

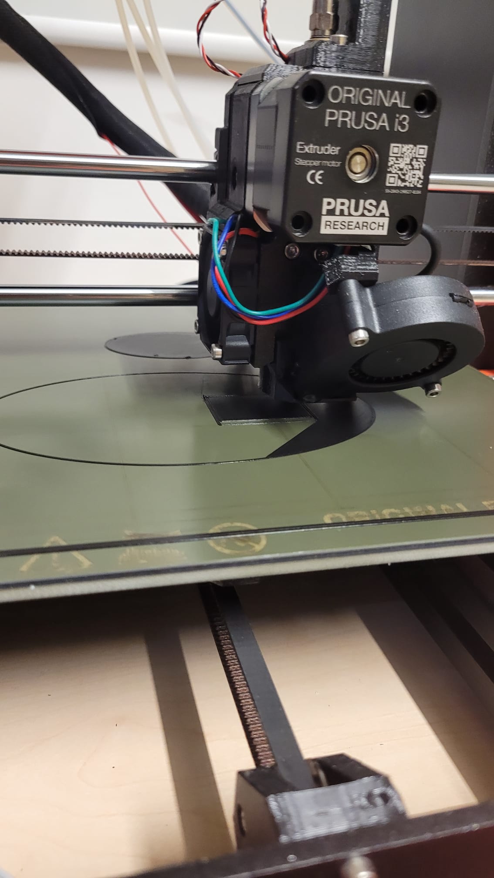
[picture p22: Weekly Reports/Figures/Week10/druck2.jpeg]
Printing First Prototype

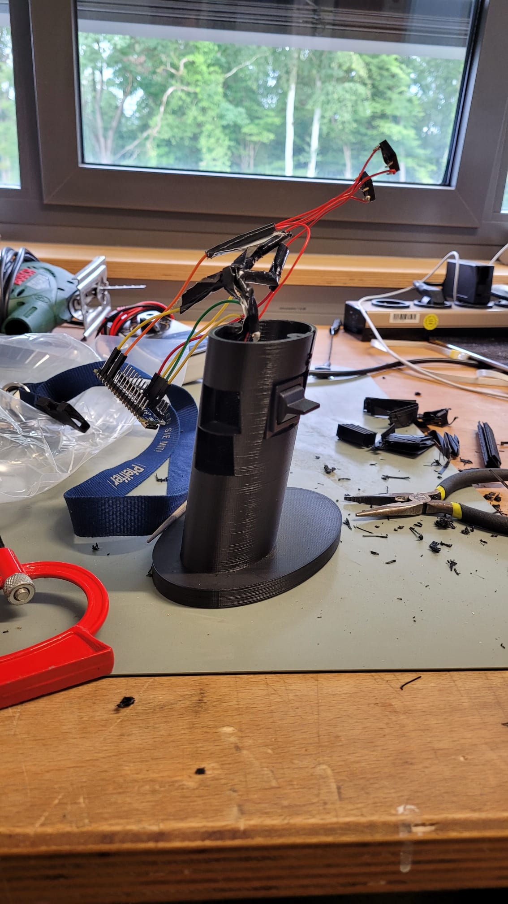
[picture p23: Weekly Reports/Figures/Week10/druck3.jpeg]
First Prototype


</details>

<details>
<summary>Current Prototype</summary>

Current Prototype
Current Prototype
Current Prototype

</details>

<details>
<summary>Cable Layout/Soldering</summary>

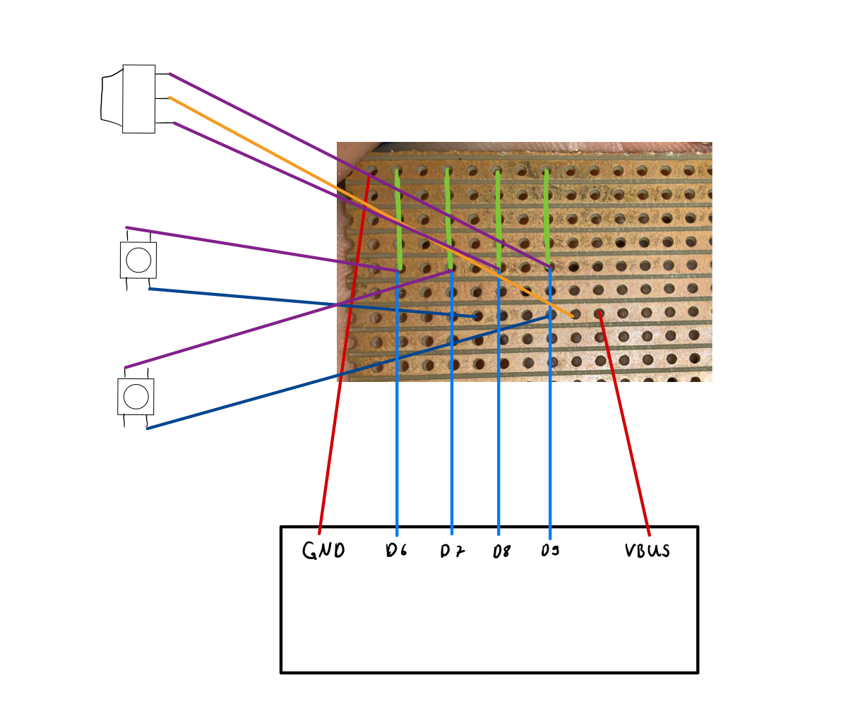
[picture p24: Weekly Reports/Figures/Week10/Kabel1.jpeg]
Initial Perfboard Idea

Current Prototype
Current Prototype
Current Prototype
Current Prototype
Current Prototype
Current Prototype

</details>

<details>
<summary>Developing Unity Environment</summary>

Current Prototype

</details>

## Milestone Review

### Achieved Milestones

1. **Milestone 1: Decide on a Design**
   - Status: Completed
   - We've successfully finalized our design concept and are satisfied with the current plan.
   - Note: The design's practicality will be fully assessed once we build the physical form.

2. **Milestone 2: Test Functionality**
   - Status: Completed
   - All individual components have been tested and integrated successfully.
   - The prototype meets our desired functionality requirements.

3. **Milestone 3: Build the Components into a Prototype**
   - Status: Completed
   - Next steps: Design a shape that accommodates all components.
   - This phase is crucial for identifying necessary design improvements.

### Pending Milestones

4. **Milestone 4: 3D Print the Spatial Mouse**
   - Status: In Progress
   - Dependent on the completion of Milestone 3.
   - Will involve 3D printing the final design and assembling all components.

## Updated Project Plan

Given our current progress, we've adjusted our project plan to focus on the final stages:

1. **Prototype Evaluation** (1 week)
   - Assess the new prototype print
   - Gather feedback from peers or potential users
   - Identify any necessary further modifications

2. **Final Design Iteration** (3-4 days)
   - Make any final adjustments based on feedback
   - Conduct a final print if required

3. **Project Finalization** (2-3 days)
   - Assemble the final version
   - Conduct final testing and documentation

We aim to complete these tasks within the next three weeks, aligning with our project deadline. This revised plan allows for iterative improvements and ensures we deliver a fully functional spatial mouse prototype.

## User Study

This project includes a user study to evaluate the usability and effectiveness of the SpatialMouse in a virtual reality (VR) context. The study is designed to assess how users interact with the SpatialMouse when manipulating 3D objects in a simulated environment.

### Study Procedure

1. Introduction
   - Welcome participants
   - Introduce the researcher
   - Explain the SpatialMouse and its purpose
   - Outline the study's objectives

2. Study Overview
   - Present a simulation model (Uterus Frozen tissue)
   - Demonstrate setting up the SpatialMouse probe
   - Explain the main task: Using the SpatialMouse to move 4 objects from a screen into a VR environment

3. Data Collection Methods
   - Think-aloud protocols during task performance
   - Short questionnaires at multiple stages
   - Observation of user interactions

4. Study Flow
   - Obtain participant consent
   - Administer initial short questionnaire
   - Conduct first think-aloud session with SpatialMouse
   - Administer second short questionnaire
   - Conduct second think-aloud session
   - Administer final short questionnaire

5. Objectives
   - Assess user experience with the SpatialMouse in a VR context
   - Identify potential usability issues or areas for improvement
   - Gather feedback on the effectiveness of the SpatialMouse for manipulating 3D objects in VR

We will hand out [this](./Figures/study-2.pdf) consent sheet and [this](./Figures/SpatialMouseAlle.pdf) questionnaires.

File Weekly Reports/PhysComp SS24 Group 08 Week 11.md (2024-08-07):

# PhysComp SS23 Assignment - Week 11

> **Deadline:** 09.07.2024, 23:59 CEST

## Weekly Progress Report
1.	**Progress Report:** What have you achieved this week with regards to your project? As usual, if your *concept* has changed, briefly describe this (and post pictures). Report on your progress in *developing your prototype*.

This week we started off by building all of our hardware components into the prototype which we developed last week. During assembly we encountered space issues, since it was quite difficult to fit everything into the body of the spatial mouse. However, after making some modification (cracking open the lower front of the grip), we were able to accomodate for the missing space. With this is was also possible to connect the Arduino to the computer without removing all the buttons. However, we will have to think about these issues for a possible future prototype.

After assembling the components into the 3D printed body and testing it out ourselves, we conducted user studies with 3 participants in order to get our first impressions on our spatial mouse.

Based on the results of our studies, we thought about how to improve our concept in order to improve the user experience of the spatial mouse. 

In addition to that, we keept working on the unity project, which now handels the input of the Spatial Mouse pretty good. But there are still some small bugs which need to be fixed.

This is a example video of the use of the prototype in action:

Prototype

2. **Evaluation Report**

    a) Report on your usability testing with a think **aloud study**.
    -	Whom did you evaluate with (3 users)? When, where, how did you recruit your users?

    All 3 evaluations were conducted consecutively on Wednesday (we started during the lecture slot) in the Mediaroom. This was necessary, since we need the computer located in the Mediaroom for our testing environment. We recruited one participant of the Physical Computing course and 2 fellow computer science students. We simply asked them if they are interested in participating in a study which will take up 20-30 minutes of their time.

    -	What functionality did you test, what did you fake (Wizard of Oz)?

    Fortunately, we were able to test our full functionality and were not forced to fake anything.
    We tested the mouse and VR component of our spatial mouse, as well the two input buttons and the tactile switch.

    -	What instructions did you give the users? What tasks did you ask them to do?

   First we asked some general questions about the users, to gather information about their experience, etc.
   We then asked them to grab the device and think aloud while they explore the spatial mouse. Afterwards, we asked them questions about the exploration in order to collect feedback.
   Lastly, we instructed them to complete the Unity task which we created over the past weeks. Here the participants also needed to share they thoughts while completing the task. Afterwards we again asked questions to our participants.

    -	What are your main observations and findings? Does your overall idea work? Did any unexpected issues occur?

    One of our main observations were that the tactile switch on the side of our spatial mouse was not fixated well enough, leading to dislocation when being used extensively. Additionally, the mouse sensitivity was too high, leading to all participants struggling with the mouse component functionality.
   Another main finding was that the function of the tactile switch (which is responsible for scrolling) was not immediately clear to the users. While all other inputs were obvious, the participants had various ideas about what the switch might do.

    b) Report on any **additional evaluation techniques** that you used:

    We complemented the think aloud study with a survey.

    -	What did you find out and how?

    With the help of the questionnaire, we encouraged the participants even more to think about what was good/bad about the usage of the spatial mouse. Some of our main findings stem from the survey which we conducted after the practical parts of our study.

    c) Finally, what **conclusions** do you draw from your evaluation? 

    From our evaluations we conclude that our overall concept is already quite good. Our conecept allows for an ergonomic hand grip. The layout was fairly intuitive (except for the tactile switch).

    On the other hand, even though the general shape goes into the right direction, the current shape is not yet perfect and needs further adjustments.
    
    - How can/should/will you change your *concept* (sketches/story boards)? 

    We will keep our general concept. However we will try to improve some functionalities:

    Firstly, we will try to improve the mouse functionality (mainly by lowering the mouse a constant scroll speed is possible with the tactile switch.sensitivity), as well as fixating the input buttons more thoroughly. We have problems with the mouse sensitivity since we first tried out the sensor. We already tried a lot of different things to improve the mouse function in the code, but it does not really get better. In the worst case we have to try another mouse sensor (if there would be other mouse sensors in the internet).
    Furthermore, we will try to reduce the issues regarding space for all hardware components in our spatial mouse. Lastly, our device does not yet work properly when using only a battery instead of a cable as power source. 

    - Which of these changes can you actually realize in your *prototype* (think both about ideal and feasible changes for the next 2 weeks)?

    Hopefuly we are able to realize all of the above changes.

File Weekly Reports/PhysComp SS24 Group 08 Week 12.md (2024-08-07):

# PhysComp SS23 Assignment - Week 12

> **Deadline:** 16.07.2024, 23:59 CEST

# Weekly Progress Report

## Overview

This week marked significant advancements in our Spatial Mouse prototype development. We focused on refining both software and hardware components, addressing key usability issues, and attempting to create an improved physical model.

## Software Improvements

Our team made substantial progress in optimizing the Arduino code and enhancing the Unity project integration:

- We fine-tuned the mouse sensitivity in our Arduino code, resolving cursor tracking issues that had been hampering user experience.
- A clever delay mechanism was implemented to smoothen the transition between mouse and VR controller modes, eliminating accidental mode switches.
- In our Unity project, we tackled the challenging issue of cursor confinement in the VR environment. We developed a keyboard shortcut system (using the 'L' key) that allows users to lock and unlock the cursor to the Unity window, greatly improving overall usability.

It's worth noting that we still observe a minor Bluetooth signal delay, likely due to the low-energy Bluetooth version used with our Arduino nano ESP32. While noticeable, we've determined this doesn't significantly impact usability for our current prototype stage.

## Hardware Enhancements

On the hardware front, we made several key improvements to our prototype design:

1. We completely redesigned the casing to better accommodate internal components, addressing previous space constraints.
2. A dedicated On/Off switch was integrated for improved power management.
3. The Spatial Mouse body is now designed in two parts for easier assembly, complemented by a new lid design.
4. We reduced tolerances for 3D printed pieces, aiming for a tighter, more precise fit.
5. Internal cable lengths were optimized to make better use of the limited space.

These changes collectively aim to create a more robust, user-friendly device that's easier to assemble and maintain.

## 3D Printing Attempt

In an effort to bring our improved design to life, we initiated a 3D print using a smaller nozzle (0.25mm) for higher accuracy. Unfortunately, we encountered technical difficulties with the printer, resulting in an unsuccessful print and damage to the equipment.

Prototype

## Challenges and Lessons Learned

The 3D printer incident has been a valuable learning experience. It underscores the importance of proper equipment handling and the need to seek expert assistance when facing complex technical issues. We're taking this as an opportunity to deepen our understanding of 3D printing processes and equipment maintenance.

Despite the setback with the 3D printing, we're excited about the progress we've made and remain committed to bringing the Spatial Mouse project to fruition. This experience has not only advanced our technical skills but also strengthened our project management and problem-solving abilities.

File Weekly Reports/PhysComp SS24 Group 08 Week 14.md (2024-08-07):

# PhysComp SS24 Assignment - Week 14

> **Deadline:** 01.08.2024, 23:59 CEST

To wrap up this course, we're giving you *one final assignment*, in which you hand in any remaining materials.

## Final Submission

Our prototype is a Spatial Mouse, which is a combination of a traditional computer mouse and a VR controller. It shall enable the user to have both functionalities without needing to switch between two separate devices.

### What works: 
- Mouse functionality (Motion sensor, buttons for left and right click, tactile switch for scrolling)
- VR functionality
- On/Off switch

### Limitations:
- Motion sensor has a short delay

### Future improvements:

- Remove the motion sensor delay
- Replace buttons for improved feedback
- Consider replacing the Scroll Switch with a scroll wheel or a small joystick to allow gradual instead of constant scrolling
- Incorporate methods to reduce power consumption (deep sleep of the arduino, ...)
- Add modal (auditive) feedback
- Conduct more user studies to find better sizes for having improved universal fit for various hand sizes

2. In this post, include a **video of your final prototype in action** (e.g., the one from your slides). This is what will survive, even after your prototypes are take apart.

    You should aim for *~2 minutes* and add a *title screen* with your (1) project name, (2) your group number, and (3) your names of course.

3. Ensure that all your **source code, design files, etc.** are in your GitLab repository. Please **add a README.md** file in the subfolder with your project code, **listing libraries/tutorials/code sources** that you used (including links). In particular, please point out files wherein the code was **not** implemented by you. Also, please describe **how to build and run** your code.

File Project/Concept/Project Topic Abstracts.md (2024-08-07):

# PhysComp SS24 Group 8 - Project Topic Abstracts

## Members

**Robin Erb:**
"I am in the 6. Semester of Computer Science. Furthermore, I am currently employed as a student researcher at the HCI department, where I started working on the spatial mouse."

**Cedric Wiese:**
"I am in the 7. Semester of Computer Science. I am currently also employed as a student assistant at the HCI department, where I assist in the Software Project."

## Preference 1

**Spatial Mouse:**

The spatial mouse could be a clever connection between a computer mouse and a VR controller. 

There are some useful use cases for this product. 
A good example could be a designer, who designs 3D objects on a virtual monitor. The designer can use the spatial mouse for his normal 2D design program but also lift it up and grab, drag and rotate the virtual object the designer is working on, without the need of taking off the VR glasses and looking for VR controller. 

Another, simpler use case could be someone working not at a the office with multiple monitors but in a café where you dont have external monitors. A virtual monitor setup would be nice. In this case this person could use the spatial mouse to perform the normal computer work but also control VR things like dragging screens and windows to another place or changing something in the virtual surrounding.

## Preference 2

**Smart AsS:**

In today's sedentary lifestyle, maintaining a good seating posture is crucial for overall health. Unfortunately, due to laziness and unawareness, we tend not to pay enough attention to our posture.

To address this issue, we would like to design a chair which will serve as a personal posture coach, providing gentle reminders to sit up straight when needed, or get off the chair completely.

This can be achieved by utilising weight and pressure sensors within the seat, so that the chair will detect changes in posture and gives real-time feedback to the user. Additionally, the chair will be programmed to recognise and save potential profiles for individual users, including key attributes including (but not limited to) height, weight, gender and body proportion.

The prototype will cater to a wide range of users such as office workers, gamers, students and people with sedentary jobs. By integrating the physical computing principles, the project will be a tangible and interactive device that responds to user input and environmental stimulus.

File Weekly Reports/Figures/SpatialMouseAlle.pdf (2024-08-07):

# SpatialMouse

SpatialMouse; https://docs.google.com/forms/u/0/d/1gic9PRxgMAvh6RB4mKZMMhyG-rFR0SML9GufhNHub6c/printform; Seite 1 von 2; Left hand; Right hand; Yes; Little; A lot; First questionnaire; Formulare

With which hand do you use your computer mouse?
Markieren Sie nur ein Oval.

Have you ever used VR?

If yes, how much experience with VR do you have?

Dieser Inhalt wurde nicht von Google erstellt und wird von Google auch nicht unterstützt.

Markieren Sie nur ein Oval.; easy; hard
Markieren Sie nur ein Oval.; Yes

https://docs.google.com/forms/u/0/d/1B0qUVOSrN1I-pI89VF_vUCIYI1rg2HOHHVZpN-KyZ74/printform | Seite 1 von 3

2.

3.

# SpatialMouse

Second questionnaire

How difficult was it to understand the function of each button?

What was easy for you to understand?

What was hard for you to understand?

Did you know which button was for the left click and which one for the right click?

Markieren Sie nur ein Oval.; Yes

https://docs.google.com/forms/u/0/d/1B0qUVOSrN1I-pI89VF_vUCIYI1rg2HOHHVZpN-KyZ74/printform | Seite 2 von 3

Dieser Inhalt wurde nicht von Google erstellt und wird von Google auch nicht unterstützt.

Did you know what is the purpose of the switch (thumb)?

What would be important to understand the layout of the SpatialMouse better?

## Formulare

Markieren Sie nur ein Oval.; Pleasant; Not pleasant

https://docs.google.com/forms/u/0/d/1alSBA1wN6piQewLxJvHgHeFs7xcrej0OveU4nPmBO8k/printform | Seite 1 von 3

# SpatialMouse

Third questionnaire

What was easy/good when working with the SpatialMouse?

What was hard/bad when working with the SpatialMouse?

How did you like the hand position while using the SpatialMouse as a mouse?

Markieren Sie nur ein Oval.; Pleasant; Not pleasant; Of corse; Never; What cloud have been/worked better?

https://docs.google.com/forms/u/0/d/1alSBA1wN6piQewLxJvHgHeFs7xcrej0OveU4nPmBO8k/printform | Seite 2 von 3

Dieser Inhalt wurde nicht von Google erstellt und wird von Google auch nicht unterstützt.

How did you like the hand position while using the SpatialMouse as a VR controller?

Could you imagine to work with the SpatialMouse for a longer period of time?

## Formulare

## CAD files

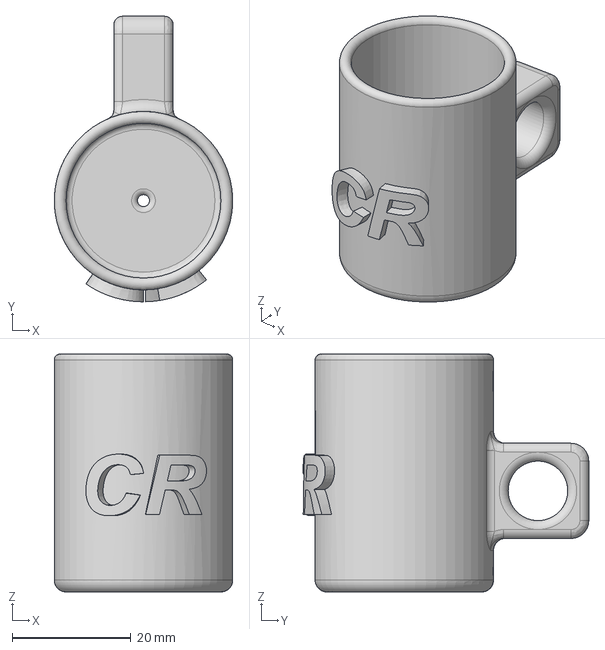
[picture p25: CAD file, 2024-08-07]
Weekly Reports/3D models/Cup/cr1mug.step
30.0 x 48.0 x 40.0 mm

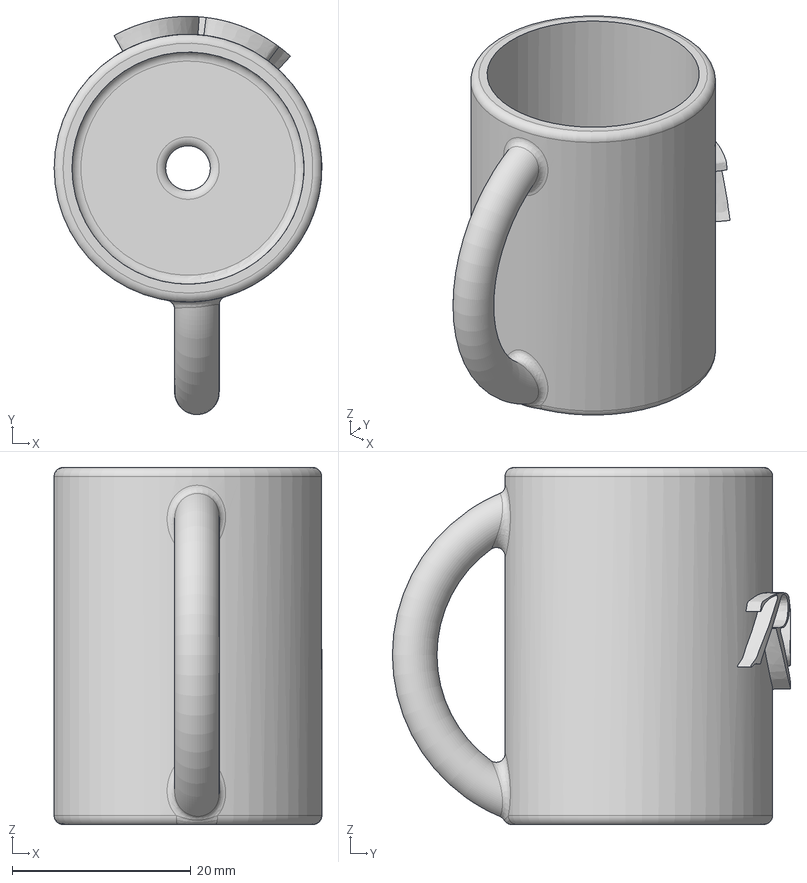
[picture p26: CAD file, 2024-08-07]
Weekly Reports/3D models/Cup/TasseRC.step
30.0 x 44.6 x 40.0 mm

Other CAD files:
Project/Mechanical/SpatialMouseFinal.f3d
Project/Mechanical/SpatialMouseV2.f3d
Weekly Reports/3D models/Spatial Mouse/SpatialMouseFinal.f3d
